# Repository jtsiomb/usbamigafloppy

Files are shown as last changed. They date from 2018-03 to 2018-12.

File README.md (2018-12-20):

USB floppy controller for Amiga disks
=====================================

This is a USB floppy disk controller, for reading and writing amiga disks. In
conjunction with the accompanying `amigafloppy` program, it allows archiving
amiga disks as ADF disk images, or writing ADF disk images back to disks, to use
with an Amiga computer.

The firmware for this controller is based on the ArduinoFloppyDiskReader
project by Rob Smith (https://github.com/RobSmithDev/ArduinoFloppyDiskReader),
converted to run on standalone AVR hardware (as opposed to an arduino) by John
Tsiombikas.

The new AVR hardware is designed to be compatible with the original host
software, so you may use the `AmigaFloppyReader` or `AmigaFloppyReaderWin`
programs from Rob's project, if you prefer.

Directory structure:

  * `hw` - hardware: kicad files and pdf schematics.
  * `fw` - firmware for the AVR microcontroller.
  * `amigafloppy` - host program for reading/writing ADF images.

Note: The `amigafloppy` host program is not completed yet. And it's not a high
priority, since Rob's original .NET programs seem to work fine with wine on
GNU/Linux. I'd like to complete it at some stage, but I can't say when that will
happen. Contributions are of course welcome, but please coordinate with me
first. Until then, please use `AmigaFloppyReader` or `AmigaFloppyReaderWin`.

Hardware License
----------------
Copyright (C) 2018 John Tsiombikas <nuclear@member.fsf.org>

The hardware of this project is released as free/open hardware under the
Creative Commons Attribution Share-Alike license. See `LICENSE.hw` for details.

Firmware License
----------------
Copyright (C) 2017 Rob Smith <rob@robsmithdev.co.uk>

Copyright (C) 2018 John Tsiombikas <nuclear@member.fsf.org>

The microcontroller firmware of this project is released as free software,
under the terms of the GNU General Public License v3, or later.  See
`LICENSE.sw` for details.

Software License
----------------
Copyright (C) 2018 John Tsiombikas <nuclear@member.fsf.org>

The host software (amigafloppy tool) is released as free software, under the
terms of the GNU General Public License v3, or later. See `LICENSE.sw` for
details.

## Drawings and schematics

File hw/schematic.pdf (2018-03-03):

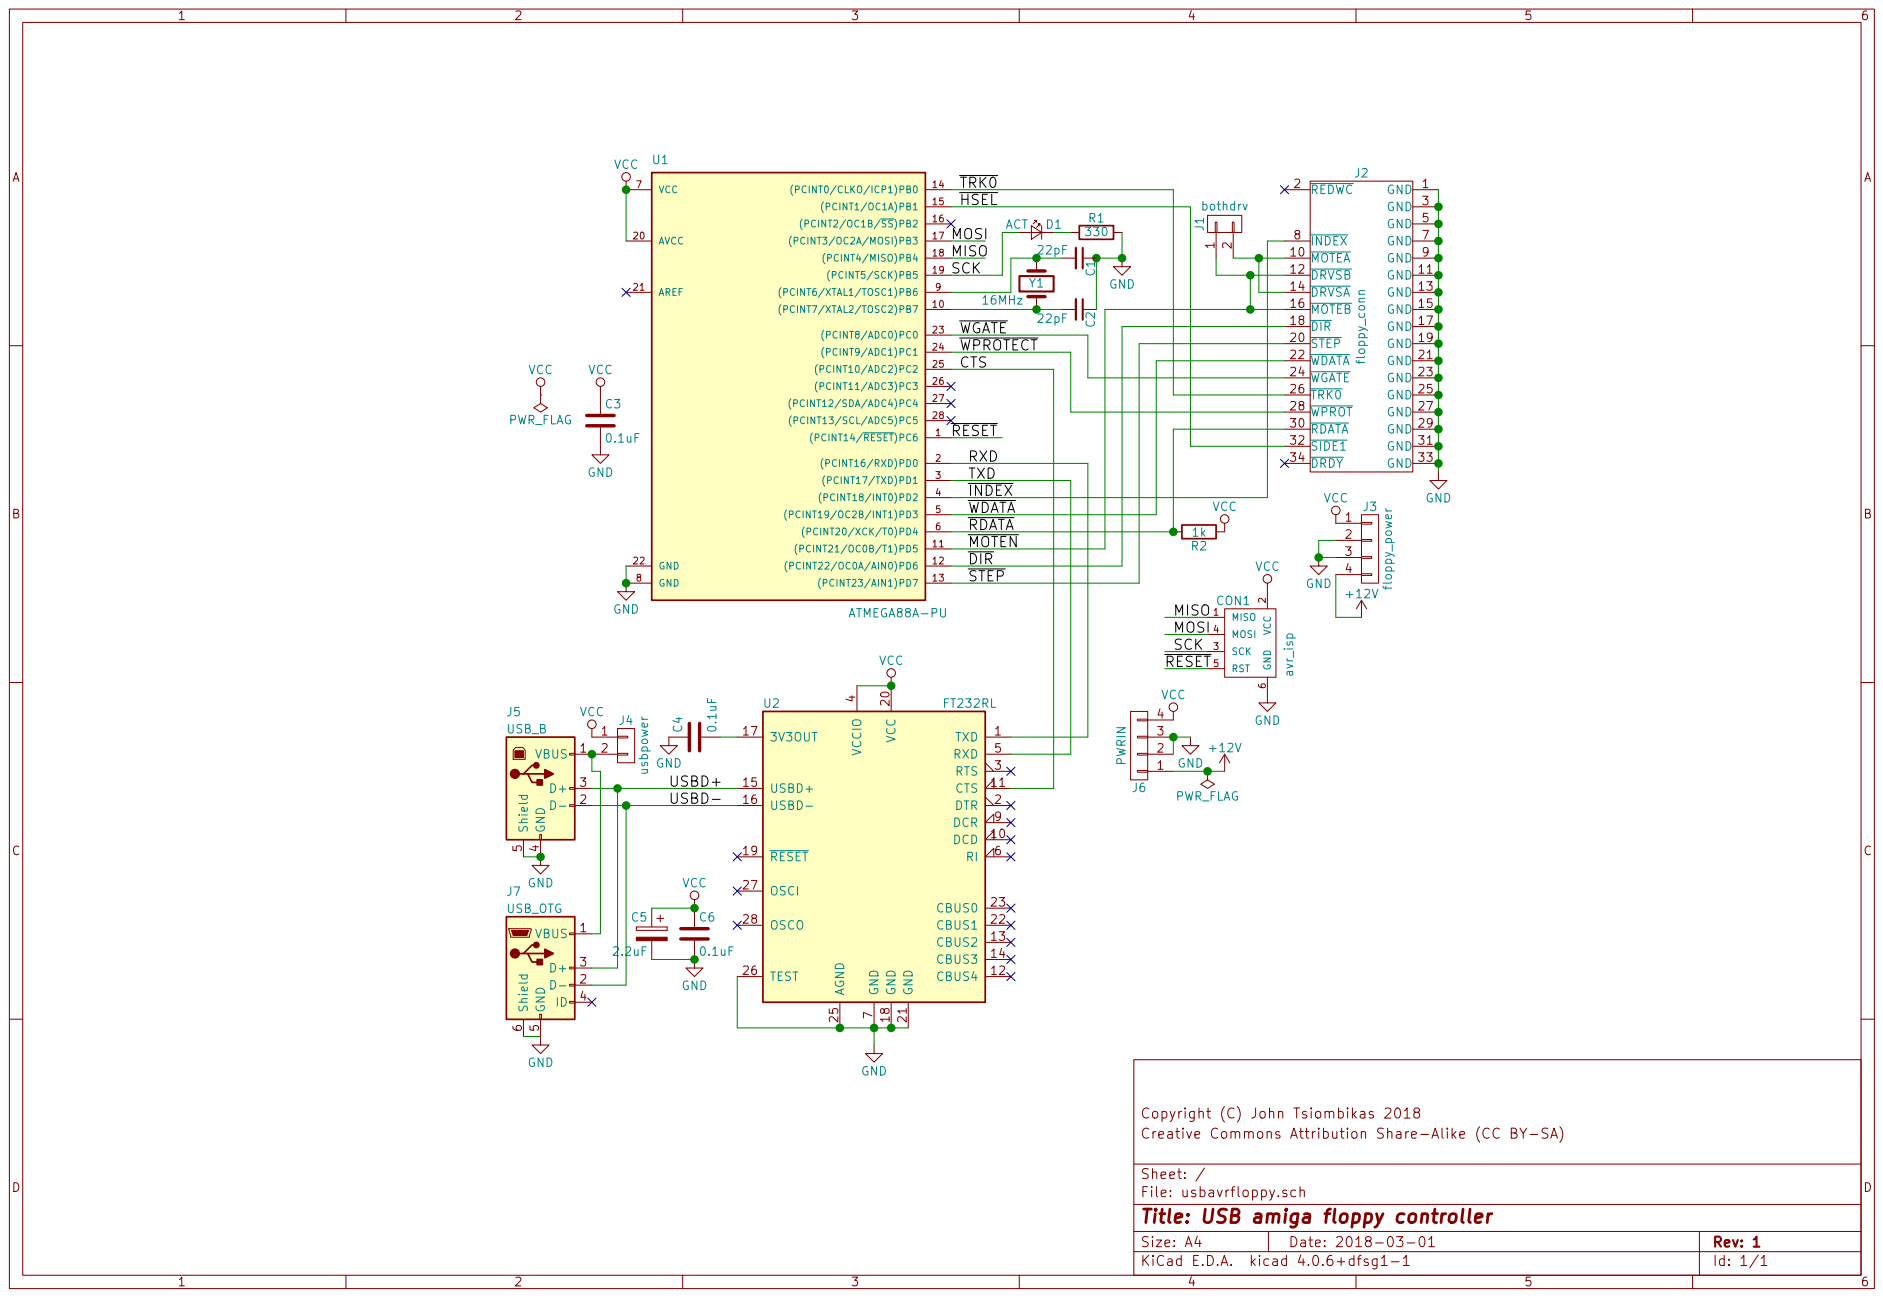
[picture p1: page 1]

Copyright (C) John Tsiombikas 2018
File: usbavrfloppy.sch Sheet: / Creative Commons Attribution Share-Alike (CC BY-SA)

Id: 1/1 Title: USB amiga floppy controller

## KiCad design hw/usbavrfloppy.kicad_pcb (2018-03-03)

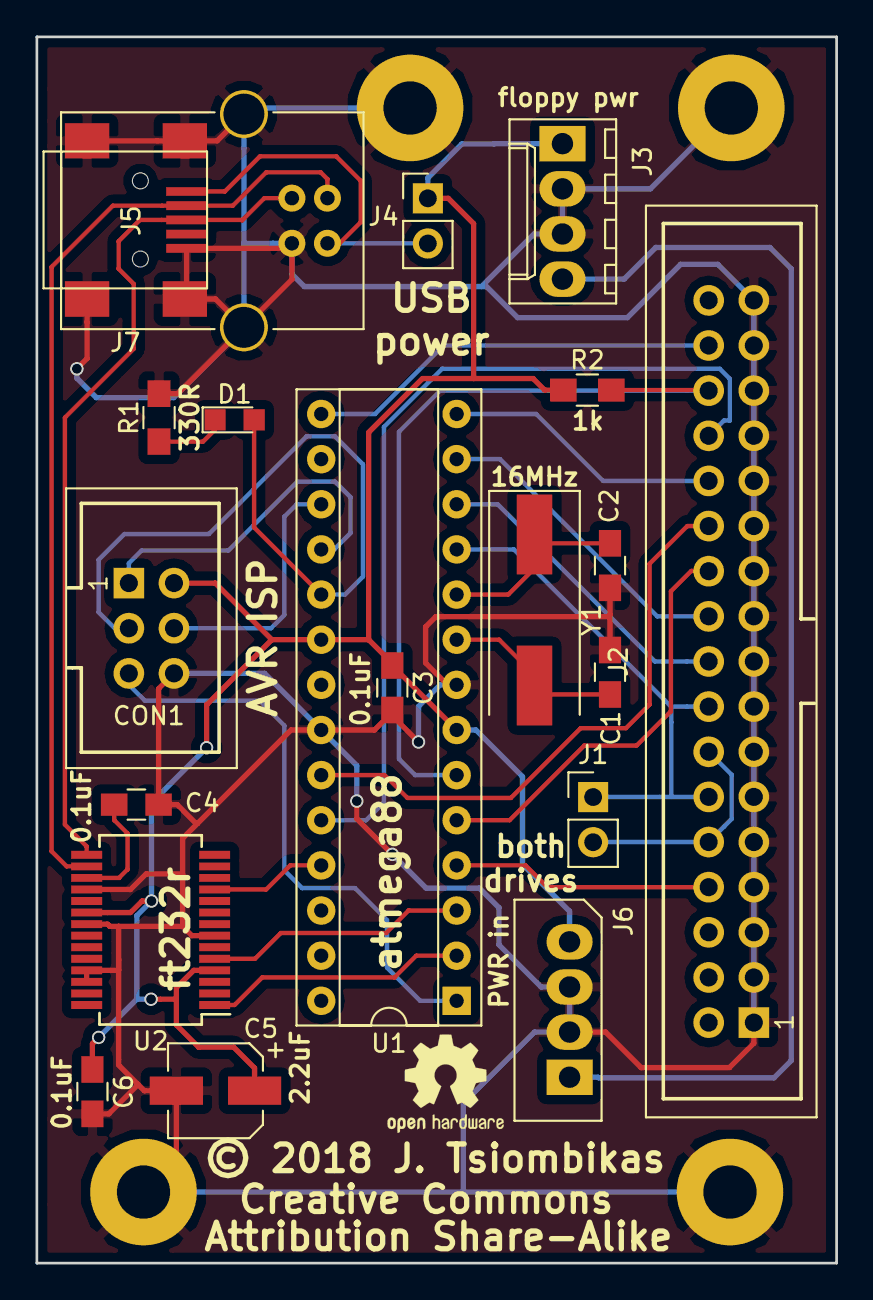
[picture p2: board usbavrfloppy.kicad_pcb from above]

Board: 2 copper layers, 45.0 x 69.0 mm, 20 parts (0 on the bottom side), 28 nets.

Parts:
C1, C2: 22pF; C_0805_HandSoldering
C3, C4, C6: 0.1uF; C_0805_HandSoldering
C5: 2.2uF; CP_Elec_5x5.7
CON1: avr_isp; IDC_Header_Straight_6pins
D1: ACT; LED_0805
J1: bothdrv; Pin_Header_Straight_1x02_Pitch2.54mm
J2: floppy_conn; IDC_Header_Straight_34pins
J3: floppy_power; Molex_KK-6410-04_04x2.54mm_Straight
J4: usbpower; Pin_Header_Straight_1x02_Pitch2.54mm
J5: USB_B
J6: PWRIN; Molex_SPOX-5267_22-03-5045_04x2.54mm_Straight
J7: USB_OTG; USB_Mini-B
R1: 330; R_0805_HandSoldering
R2: 1k; R_0805_HandSoldering
U1: ATMEGA88A-PU; DIP-28_W7.62mm_Socket
U2: FT232RL; SSOP-28_5.3x10.2mm_Pitch0.65mm
Y1: 16MHz; Crystal_SMD_HC49-SD

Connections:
+12V: J3.4, J6.1
/CTS: U1.25, U2.11
/MISO: CON1.1, U1.18
/MOSI: CON1.4, U1.17
/RXD: U1.2, U2.1
/SCK: CON1.3, D1.2, U1.19
/TXD: U1.3, U2.5
/USBD+: J5.3, J7.3, U2.15
/USBD-: J5.2, J7.2, U2.16
/~DIR: J2.18, U1.12
/~HSEL: J2.32, U1.15
/~INDEX: J2.8, U1.4
/~MOTEN: J1.1, J2.12, J2.16, U1.11
/~RDATA: J2.30, R2.2, U1.6
/~RESET: CON1.5, U1.1
/~STEP: J2.20, U1.13
/~TRK0: J2.26, U1.14
/~WDATA: J2.22, U1.5
/~WGATE: J2.24, U1.23
/~WPROTECT: J2.28, U1.24
GND: C1.1, C2.1, C3.2, C4.1, C5.2, C6.2, CON1.6, J2.1, J2.3, J2.5, J2.7, J2.9, J2.11, J2.13, J2.15, J2.17, J2.19, J2.21, J2.23, J2.25, J2.27, J2.29, J2.31, J2.33, J3.2, J3.3, J5.4, J5.5, J6.2, J6.3, J7.5, J7.6, R1.2, U1.8, U1.22, U2.7, U2.18, U2.21, U2.25, U2.26
unnamed: C1.2, U1.9, Y1.2
unnamed: C2.2, U1.10, Y1.1
unnamed: C4.2, U2.17
unnamed: D1.1, R1.1
unnamed: J1.2, J2.10, J2.14
unnamed: J4.2, J5.1, J7.1
VCC: C3.1, C5.1, C6.1, CON1.2, J3.1, J4.1, J6.4, R2.1, U1.7, U1.20, U2.4, U2.20

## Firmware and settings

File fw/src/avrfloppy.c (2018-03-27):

/* USB floppy controller for amiga disks
 *
 * Copyright (C) 2017-2018 Robert Smith (@RobSmithDev)
 * Copyright (C) 2018 John Tsiombikas <nuclear@member.fsf.org>
 *
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
 * You should have received a copy of the GNU Library General Public
 * License along with this program; if not, see http://www.gnu.org/licenses
 */
/* Ported from arduino to standalone AVR by John Tsiombikas */

#include <avr/io.h>
#include <avr/interrupt.h>


#define INDEX_PORT			PIND
#define INDEX_BIT			0x04

#define WDATA_PORT			PORTD
#define WDATA_BIT			0x08

#define RDATA_PORT			PIND
#define RDATA_BIT			0x10

#define MOTOR_PORT			PORTD
#define MOTOR_ENABLE_BIT	0x20
#define MOTOR_DIR_BIT		0x40
#define MOTOR_STEP_BIT		0x80

#define TRACK0_PORT			PINB
#define TRACK0_BIT			0x01

#define HEADSEL_PORT		PORTB
#define HEAD_SELECT_BIT		0x02

#define WGATE_PORT			PORTC
#define WGATE_BIT			0x01

#define WPROT_PORT			PINC
#define WPROT_BIT			0x02

#define CTS_PORT			PORTC
#define CTS_BIT				0x04

#define LED_PORT			PORTB
#define LED_BIT				0x20

#define BAUDRATE 2000000

#define BAUD_PRESCALLER_NORMAL_MODE	  (((F_CPU / (BAUDRATE * 16UL))) - 1)
#define BAUD_PRESCALLER_DOUBLESPEED_MODE (((F_CPU / (BAUDRATE * 8UL))) - 1)
/* We're using double speed mode */
#define UART_USE_DOUBLESPEED_MODE

/* Motor directions for PIN settings */
#define MOTOR_TRACK_DECREASE   1
#define MOTOR_TRACK_INCREASE   0
#define MOTOR_DIR(x) ((x) ? (MOTOR_PORT |= MOTOR_DIR_BIT) : (MOTOR_PORT &= ~MOTOR_DIR_BIT))

/* Paula on the Amiga used to find the SYNC WORDS and then read 0x1900 further WORDS.
 * A dos track is 11968 bytes in size, theritical revolution is 12800 bytes.
 * Paula assumed it was 12868 bytes, so we read that, plus thre size of a sectors
 */
#define RAW_TRACKDATA_LENGTH   (0x1900 * 2 + 0x440)

static void setup(void);
static void loop(void);
static void smalldelay(unsigned long delay_time);
static void step_direction_head(void);
static void prep_serial_interface(void);
static inline unsigned char read_byte_from_uart(void);
static inline void write_byte_to_uart(const char value);
static int goto_track0(void);
static int goto_track_x(void);
static void write_track_from_uart(void);
static void erase_track(void);
static void read_track_data_fast(void);
static void run_diagnostic(void);

static int current_track; /* The current track that the head is over */
static int drive_enabled; /* If the drive has been switched on or not */
static int in_write_mode; /* If we're in WRITING mode or not */

int main(void)
{
	setup();
	for(;;) {
		loop();
	}
	return 0;
}

static void setup(void)
{
	DDRB = 0x22;	/* outputs: 1 (head sel), 5 (act LED) */
	DDRC = 0xf5;	/* outputs: 0 (wr.gate), 2 (cts) */
	DDRD = 0xe8;	/* outputs: 3 (write), 5 (motor en), 6 (dir), 7 (step) */

	/* Do these right away to prevent the disk being written to */
	PORTC = WGATE_BIT | WPROT_BIT;	/* write gate off and pullup on pin 1 (wprot) */
	PORTD = WDATA_BIT | RDATA_BIT;	/* write data hight and pullup on pin 4 (read) */
	PORTB = TRACK0_BIT;				/* pullup on track0 detect */

	MOTOR_PORT |= MOTOR_ENABLE_BIT;
	HEADSEL_PORT &= ~HEAD_SELECT_BIT;

	/* Disable all interrupts - we dont want them! */
	cli();

	/* Setup the USART */
	prep_serial_interface();
}


/* The main command loop */
static void loop(void)
{
	unsigned char command;

	CTS_PORT &= ~CTS_BIT;		/* Allow data incoming */
	WGATE_PORT |= WGATE_BIT;   /* always turn writing off */

	/* Read the command from the PC */
	command = read_byte_from_uart();

	switch(command) {
	case '?':
		/* Command: "?" Means information about the firmware */
		write_byte_to_uart('1');  /* Success */
		write_byte_to_uart('V');  /* Followed */
		write_byte_to_uart('1');  /* By */
		write_byte_to_uart('.');  /* Version */
		write_byte_to_uart('3');  /* Number */
		break;

		/* Command "." means go back to track 0 */
	case '.':
		if(!drive_enabled) {
			write_byte_to_uart('0');
		} else {
			if(goto_track0() != -1) {	/* reset */
				write_byte_to_uart('1');
			} else {
				write_byte_to_uart('#');
			}
		}
		break;

	case '#':
		/* Command "#" means goto track.  Should be formatted as #00 or #32 etc */
		if(!drive_enabled) {
			read_byte_from_uart();
			read_byte_from_uart();
			write_byte_to_uart('0');
		} else {
			if(goto_track_x()) {
				smalldelay(100); /* wait for drive */
				write_byte_to_uart('1');
			} else {
				write_byte_to_uart('0');
			}
		}
		break;

	case '[':
		/* Command "[" select LOWER disk side */
		HEADSEL_PORT &= ~HEAD_SELECT_BIT;
		write_byte_to_uart('1');
		break;

	case ']':
		/* Command "]" select UPPER disk side */
		HEADSEL_PORT |= HEAD_SELECT_BIT;
		write_byte_to_uart('1');
		break;

	case '<':
		/* Command "<" Read track from the drive */
		if(!drive_enabled) {
			write_byte_to_uart('0');
		} else {
			write_byte_to_uart('1');
			read_track_data_fast();
		}
		break;

	case '>':
		/* Command ">" Write track to the drive */
		if(!drive_enabled) {
			write_byte_to_uart('0');
		} else {
			if(!in_write_mode) {
				write_byte_to_uart('0');
			} else {
				write_byte_to_uart('1');
				write_track_from_uart();
			}
		}
		break;

	case 'X':
		/* command "X" Erase current track (writes 0xAA to it) */
		if(!drive_enabled) {
			write_byte_to_uart('0');
		} else {
			if(!in_write_mode) {
				write_byte_to_uart('0');
			} else {
				write_byte_to_uart('1');
				erase_track();
			}
		}
		break;

	case '-':
		/* Turn off the drive motor */
		MOTOR_PORT |= MOTOR_ENABLE_BIT;
		WGATE_PORT |= WGATE_BIT;
		drive_enabled = 0;
		write_byte_to_uart('1');
		in_write_mode = 0;
		break;

	case '+':
		/* Turn on the drive motor and setup in READ MODE */
		if(in_write_mode) {
			/* Ensure writing is turned off */
			MOTOR_PORT |= MOTOR_ENABLE_BIT;
			WGATE_PORT |= WGATE_BIT;
			smalldelay(100);
			drive_enabled = 0;
			in_write_mode = 0;
		}
		if(!drive_enabled) {
			MOTOR_PORT &= ~MOTOR_ENABLE_BIT;
			drive_enabled = 1;
			smalldelay(750); /* wait for drive */
		}
		write_byte_to_uart('1');
		break;

	case '~':
		/* Turn on the drive motor and setup in WRITE MODE */
		if(drive_enabled) {
			WGATE_PORT |= WGATE_BIT;
			MOTOR_PORT |= MOTOR_ENABLE_BIT;
			drive_enabled = 0;
			smalldelay(100);
		}
		/* We're writing! */
		WGATE_PORT &= ~WGATE_BIT;
		/* Gate has to be pulled LOW BEFORE we turn the drive on */
		MOTOR_PORT &= ~MOTOR_ENABLE_BIT;
		/* Raise the write gate again */
		WGATE_PORT |= WGATE_BIT;
		smalldelay(750); /* wait for drive */

		/* At this point we can see the status of the write protect flag */
		if((WPROT_PORT & WPROT_BIT) == 0) {
			write_byte_to_uart('0');
			in_write_mode = 0;
			MOTOR_PORT |= MOTOR_ENABLE_BIT;
			/*WGATE_PORT |= WGATE_BIT;*/
		} else  {
			in_write_mode = 1;
			drive_enabled = 1;
			write_byte_to_uart('1');
		}
		break;

	case '&':
		run_diagnostic();
		break;

	default:
		/* We don't recognise the command! */
		write_byte_to_uart('!'); /* error */
		break;
	}
}


/* Because we turned off interrupts delay() doesnt work! */
static void smalldelay(unsigned long delay_time)
{
	unsigned long i;

	delay_time *= (F_CPU / 9000);

	for(i=0; i<delay_time; ++i) {
		asm volatile("nop");
	}
}

/* Step the head once.  This seems to be an acceptable speed for the head */
static void step_direction_head(void)
{
	smalldelay(5);
	MOTOR_PORT &= ~MOTOR_STEP_BIT;
	smalldelay(5);
	MOTOR_PORT |= MOTOR_STEP_BIT;
}

/* Prepare serial port - We dont want to use the arduino serial library as we
 * want to use faster speeds and no serial interrupts
 */
static void prep_serial_interface(void)
{
#ifdef UART_USE_DOUBLESPEED_MODE
	UBRR0H = (uint8_t)(BAUD_PRESCALLER_DOUBLESPEED_MODE>>8);
	UBRR0L = (uint8_t)(BAUD_PRESCALLER_DOUBLESPEED_MODE);
	UCSR0A |= 1<<U2X0;
#else
	UBRR0H = (uint8_t)(BAUD_PRESCALLER_NORMAL_MODE>>8);
	UBRR0L = (uint8_t)(BAUD_PRESCALLER_NORMAL_MODE);
	UCSR0A &= ~(1<<U2X0);
#endif

	UCSR0B = (1 << RXEN0) | (1 << TXEN0);
	/* UsartCharacterSiZe - 8-bit */
	UCSR0C = (1 << UCSZ01) | (1 << UCSZ00);
}

/* Directly read a byte from the UART0 */
static inline unsigned char read_byte_from_uart(void)
{
	while(!(UCSR0A & (1 << RXC0)));
	return UDR0;
}

/* Directly write a byte to the UART0 */
static inline void write_byte_to_uart(const char value)
{
	while(!(UCSR0A & (1 << UDRE0)));
	UDR0 = value;
}

/* Rewinds the head back to track 0 */
static int goto_track0(void)
{
	int steps = 0;

	/* Set the direction to go backwards */
	MOTOR_DIR(MOTOR_TRACK_DECREASE);
	while((TRACK0_PORT & TRACK0_BIT)) {
		step_direction_head();	/* Keep moving the head until we see the TRACK 0 detection pin */

		if(++steps > 170) {
			/* we've stepped twice as much as the maximum possible steps needed, and still
			 * haven't reached track 0
			 */
			return -1;
		}
	}
	current_track = 0;	/* Reset the track number */
	return 0;
}

/* Goto a specific track.  During testing it was easier for the track number
 * to be supplied as two ASCII characters, so I left it like this
 */
static int goto_track_x(void)
{
	int track;
	unsigned char track1, track2;

	/* Read the bytes */
	track1 = read_byte_from_uart();
	track2 = read_byte_from_uart();

	/* Validate */
	if((track1 < '0') || (track1 > '9')) return 0;
	if((track2 < '0') || (track2 > '9')) return 0;

	/* Calculate target track and validate */
	track = ((track1 - '0') * 10) + (track2 - '0');
	if(track < 0) return 0;
	if(track > 81) return 0; /* yes amiga could read track 81! */

	/* Exit if its already been reached */
	if(track == current_track) return 1;

	/* And step the head until we reach this track number */
	if(current_track < track) {
		MOTOR_DIR(MOTOR_TRACK_INCREASE);	/* move out */
		while(current_track < track) {
			step_direction_head();
			current_track++;
		}
	} else {
		MOTOR_DIR(MOTOR_TRACK_DECREASE);	/* move in */
		while(current_track > track) {
			step_direction_head();
			current_track--;
		}
	}

	return 1;
}


/* 256 byte circular buffer -
 * don't change this, we abuse the unsigned char to overflow back to zero!
 */
#define SERIAL_BUFFER_SIZE 256
#define SERIAL_BUFFER_START (SERIAL_BUFFER_SIZE - 16)
static unsigned char SERIAL_BUFFER[SERIAL_BUFFER_SIZE];


#define CHECK_SERIAL() \
	do { \
		if(UCSR0A & (1 << RXC0)) { \
			SERIAL_BUFFER[serial_write_pos++] = UDR0; \
			serial_bytes_in_use++; \
		} else if(serial_bytes_in_use < SERIAL_BUFFER_START) { \
			CTS_PORT &= ~CTS_BIT; \
			CTS_PORT |= CTS_BIT; \
		} \
	} while(0)



/* Small Macro to write a '1' pulse to the drive if a bit is set based on the supplied bitmask */
#define WRITE_BIT(value, bitmask) \
	do { \
		if(current_byte & bitmask)  { \
			while(TCNT2 < value); \
			WDATA_PORT &= ~WDATA_BIT; \
		 } else { \
			 while(TCNT2 < value); \
			WDATA_PORT |= WDATA_BIT; \
		} \
	} while(0)

/* Write a track to disk from the UART -
 * the data should be pre-MFM encoded raw track data where '1's are the
 * pulses/phase reversals to trigger
 */
static void write_track_from_uart(void)
{
	unsigned int i, serial_bytes_in_use;
	unsigned char high_byte, low_byte, wait_for_index, current_byte;
	unsigned char serial_read_pos, serial_write_pos;
	unsigned short num_bytes;

	/* Configure timer 2 just as a counter in NORMAL mode */
	TCCR2A = 0;			/* No physical output port pins and normal operation */
	TCCR2B = (1 << CS20);	/* Prescale = 1 */

	/* Check if its write protected.
	 * You can only do this after the write gate has been pulled low
	 */
	if((WPROT_PORT & WPROT_BIT) == 0) {
		write_byte_to_uart('N');
		WGATE_PORT |= WGATE_BIT;
		return;
	}
	write_byte_to_uart('Y');

	/* Find out how many bytes they want to send */
	high_byte = read_byte_from_uart();
	low_byte = read_byte_from_uart();
	wait_for_index = read_byte_from_uart();
	CTS_PORT |= CTS_BIT;	/* stop any more data coming in! */

	num_bytes = (((unsigned short)high_byte) << 8) | low_byte;

	write_byte_to_uart('!');

	/* Signal we're ready for another byte to come */
	CTS_PORT &= ~CTS_BIT;

	/* Fill our buffer to give us a head start */
	for(i=0; i<SERIAL_BUFFER_START; i++) {
		/* Wait for it */
		while(!(UCSR0A & (1 << RXC0)));
		/* Save the byte */
		SERIAL_BUFFER[i] = UDR0;
	}

	/* Stop more bytes coming in, although we expect one more */
	CTS_PORT |= CTS_BIT;

	/* Setup buffer parameters */
	serial_read_pos = 0;
	serial_write_pos = SERIAL_BUFFER_START;
	LED_PORT |= LED_BIT;
	serial_bytes_in_use = SERIAL_BUFFER_START;

	/* Enable writing */
	WGATE_PORT &= ~WGATE_BIT;

	/* While the INDEX pin is high wait.  Might as well write from the start of the track */
	if(wait_for_index) {
		while(INDEX_PORT & INDEX_BIT);
	}

	/* Reset the counter, ready for writing */
	TCNT2 = 0;

	/* ideally we'd use an ISR here, but there's just too much overhead even with naked
	 * ISRs to do this (preserving registers, etc)
	 */
	for(i=0; i<num_bytes; i++) {
		/* Should never happen, but we'll wait here if theres no data */
		if(serial_bytes_in_use < 1) {
			/* This can't happen and causes a write failure */
			LED_PORT &= ~LED_BIT;
			/* Thus means buffer underflow. PC wasn't sending us data fast enough */
			write_byte_to_uart('X');
			WGATE_PORT |= WGATE_BIT;
			TCCR2B = 0;   /* No Clock (turn off) */
			return;
		}

		/* Read a buye from the buffer */
		current_byte = SERIAL_BUFFER[serial_read_pos++];
		serial_bytes_in_use--;

		/* there's a small possibility we actually get back here before TCNT2 overflows
		 * back to zero, causing this to write early.
		 */
		while(TCNT2 >= 240);

		/* Now we write the data. Hopefully by the time we get back to the top
		 * everything is ready again
		 */
		WRITE_BIT(0x10, 0x80);
		CHECK_SERIAL();
		WRITE_BIT(0x30, 0x40);
		CHECK_SERIAL();
		WRITE_BIT(0x50, 0x20);
		CHECK_SERIAL();
		WRITE_BIT(0x70, 0x10);
		CHECK_SERIAL();
		WRITE_BIT(0x90, 0x08);
		CHECK_SERIAL();
		WRITE_BIT(0xb0, 0x04);
		CHECK_SERIAL();
		WRITE_BIT(0xd0, 0x02);
		CHECK_SERIAL();
		WRITE_BIT(0xf0, 0x01);
	}
	WGATE_PORT |= WGATE_BIT;

	/* Done! */
	write_byte_to_uart('1');
	LED_PORT &= ~LED_BIT;

	/* Disable the 500khz signal */
	TCCR2B = 0;   /* No Clock (turn off) */
}


static void erase_track(void)
{
	int i;
	unsigned char current_byte;

	/* configure timer 2 just as a counter in NORMAL mode */
	TCCR2A = 0;		/* no physical output port pins and normal operation */
	TCCR2B = (1 << CS20);	/* prescale = 1 */

	/* check if it's write protected */
	if((WPROT_PORT & WPROT_BIT) == 0) {
		write_byte_to_uart('N');
		WGATE_PORT |= WGATE_BIT;
		return;
	}
	write_byte_to_uart('Y');

	LED_PORT |= LED_BIT;

	/* enable writing */
	WGATE_PORT &= ~WGATE_BIT;

	/* reset the counter, ready for writing */
	TCNT2 = 0;
	current_byte = 0xaa;

	/* write complete blank track - at 300rpm, 500kbps, a track takes approx 1/5
	 * second to write. this is roughly 12500 bytes. our RAW read is 13888 bytes,
	 * so we'll use that just to make sure we get every last bit.
	 */
	for(i=0; i<RAW_TRACKDATA_LENGTH; i++) {
		WRITE_BIT(0x10, 0x80);
		WRITE_BIT(0x30, 0x40);
		WRITE_BIT(0x50, 0x20);
		WRITE_BIT(0x70, 0x10);
		WRITE_BIT(0x90, 0x08);
		WRITE_BIT(0xb0, 0x04);
		WRITE_BIT(0xd0, 0x02);
		WRITE_BIT(0xf0, 0x01);

		while(TCNT2 >= 240);
	}

	/* turn the write head off */
	WGATE_PORT |= WGATE_BIT;

	/* done! */
	write_byte_to_uart('1');
	LED_PORT &= ~LED_BIT;

	/* disable the 500khz signal */
	TCCR2B = 0;	/* no clock (turn off) */
}


/* Read the track using a timings to calculate which MFM sequence has been triggered */
static void read_track_data_fast(void)
{
	unsigned char data_output_byte, counter, bits;
	long total_bits, target;

	/* Configure timer 2 just as a counter in NORMAL mode */
	TCCR2A = 0;			/* No physical output port pins and normal operation */
	TCCR2B = (1 << CS20);	/* Prescale = 1 */

	/* First wait for the serial port to be available */
	while(!(UCSR0A & (1 << UDRE0)));

	/* Signal we're active */
	LED_PORT |= LED_BIT;

	/* While the INDEX pin is high wait if the other end requires us to */
	if(read_byte_from_uart()) {
		while(INDEX_PORT & INDEX_BIT);
	}

	/* Prepare the two counter values as follows: */
	TCNT2=0;	   /* Reset the counter */

	data_output_byte = 0;
	total_bits = 0;
	target = (long)RAW_TRACKDATA_LENGTH * 8L;

	while(total_bits < target) {
		for(bits=0; bits<4; bits++) {
			/* Wait while pin is high */

			while(RDATA_PORT & RDATA_BIT);
			counter = TCNT2;
			TCNT2 = 0;  /* reset */

			data_output_byte <<= 2;

			if(counter < 80) {
				data_output_byte |= 1;
				total_bits += 2;
			} else if(counter > 111) {
				/* this accounts for just a '1' or a '01' as two '1' arent allowed in a row */
				data_output_byte |= 3;
				total_bits += 4;
			} else {
				data_output_byte |= 2;
				total_bits += 3;
			}

			/* Wait until pin is high again */
			while(!(RDATA_PORT & RDATA_BIT));
		}
		UDR0 = data_output_byte;
	}
	/* Because of the above rules the actual valid two-bit sequences output
	 * are 01, 10 and 11, so we use 00 to say "END OF DATA"
	 */
	write_byte_to_uart(0);

	/* turn off the status LED */
	LED_PORT &= ~LED_BIT;

	/* Disable the counter */
	TCCR2B = 0;	  /* No Clock (turn off) */
}

static void run_diagnostic(void)
{
	int i, state1, state2, res;
	char test;

	test = read_byte_from_uart();
	switch(test) {
	case '1':	/* turn off CTS */
		CTS_PORT &= ~CTS_BIT;
		write_byte_to_uart('1');
		read_byte_from_uart();
		write_byte_to_uart('1');
		break;

	case '2':	/* turn on CTS */
		CTS_PORT |= CTS_BIT;
		write_byte_to_uart('1');
		read_byte_from_uart();
		write_byte_to_uart('1');
		break;

	case '3':	/* index pulse test (with timeout) */
		state1 = state2 = res = 0;

		/* At the 300 RPM (5 turns per second) this runs at, this loop needs to
		 * run a few times to check for index pulses. This runs for approx 1 sec
		 */
		for(i=0; i<20 * 60000; i++) {
			if(INDEX_PORT & INDEX_BIT) {
				state1 = 1;
			} else {
				state2 = 1;
			}
			if(state1 && state2) {
				res = 1;
				break;
			}
		}
		write_byte_to_uart(res ? '1' : '0');
		break;

	case '4':	/* data pulse test (with timeout) */
		state1 = state2 = res = 0;

		for(i=0; i<20 * 60000; i++) {
			if(RDATA_PORT & RDATA_BIT) {
				state1 = 1;
			} else {
				state2 = 1;
			}
			if(state1 && state2) {
				res = 1;
				break;
			}
		}

		write_byte_to_uart(res ? '1' : '0');
		break;

	default:
		write_byte_to_uart('0');
		break;
	}
}

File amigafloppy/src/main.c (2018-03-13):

/*
amigafloppy - driver for the USB floppy controller for amiga disks
Copyright (C) 2018  John Tsiombikas <nuclear@member.fsf.org>

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
You should have received a copy of the GNU General Public License
along with this program.  If not, see <http://www.gnu.org/licenses/>.
*/
#include <stdio.h>
#include <stdlib.h>
#include "dev.h"
#include "opt.h"
#include "adf.h"

#define TRACK_SIZE		(0x1900 * 2 + 0x440)
#define NUM_TRACKS		80

static void print_progress(int cyl, int head);

int main(int argc, char **argv)
{
	int i, j, num_tries, res, status = 1;
	unsigned char buf[TRACK_SIZE];

	if(init_options(argc, argv) == -1) {
		return 1;
	}

	if(init_device(opt.devfile) == -1) {
		return 1;
	}

	if(adf_open(opt.fname) == -1) {
		shutdown_device();
		return 1;
	}

	begin_read();
	for(i=0; i<NUM_TRACKS; i++) {
		move_head(i);
		for(j=0; j<2; j++) {
			select_head(j);

			num_tries = opt.retries;
			while((res = read_track(buf)) == -1 && num_tries-- > 0);
			if(res == -1) {
				fprintf(stderr, "failed to read track %d side %d\n", i, j);
				goto done;
			}

			if(adf_write_track(buf) == -1) {
				fprintf(stderr, "failed to write track %d side %d to ADF image\n", i, j);
				goto done;
			}
			if(opt.verbose) {
				print_progress(i, j);
			}
		}
	}
	putchar('\n');
	status = 0;

done:
	end_access();
	adf_close();
	shutdown_device();
	if(status != 0) {
		remove(opt.fname);
	}
	return status;
}

static void print_progress(int cyl, int head)
{
	int i, p, count;

	p = ((cyl << 1) | head) * 100 / ((NUM_TRACKS - 1) * 2);
	count = p / 2;

	printf("Reading (C:%02d H:%d) [", cyl, head);

	for(i=0; i<50; i++) {
		if(i < count || count == 50) {
			putchar('=');
		} else if(i == count) {
			putchar('>');
		} else {
			putchar(' ');
		}
	}

	printf("] %d%%  \r", p);
	fflush(stdout);
}

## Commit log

2018-03-08 changed the copyright statements in the readme file to reflect the decision to not include any of the original AmigaReader code, and re-write the host-side driver program from scratch.
2018-03-27 backported Rob's changes from firmware 1.3, which fixes the write checksum errors
    [avrfloppy.c]

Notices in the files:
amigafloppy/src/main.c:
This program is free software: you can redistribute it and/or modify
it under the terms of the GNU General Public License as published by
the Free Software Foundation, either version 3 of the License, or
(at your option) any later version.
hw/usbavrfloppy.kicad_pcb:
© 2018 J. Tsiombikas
